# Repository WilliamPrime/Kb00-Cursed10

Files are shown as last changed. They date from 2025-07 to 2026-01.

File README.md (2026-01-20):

This was a shortish project where i wanted to make my own keyboard with my own layout.

The reason for wanting to do this was that i have limited desk space so i prefer a smaller more compact keyboard, so as of currently i use a 65% keyboard
however i do miss having a full size num pad and FN keys so i wanted to create a layout, and keyboard that would focus on getting a full key layout but making it more compact



# some pictures of the project

RENDER 1





# BOM

|part |cost  |notes |link |
|---|---|---|---|
|keycaps |19.97 | |https://www.aliexpress.com/item/1005005981079053.html|
|PCB |43 |JLC! | |
|Switches|34.19 |clicky clicky! |https://www.aliexpress.com/item/1005007779640100.html|
|Diodes  |3.1 |need 2 lots of 1.55 |https://www.aliexpress.com/item/1005006127068810.html|
|PI pico |2.17  |pico with usb type c|https://www.aliexpress.com/item/1005003753933847.html|
|PLA |0 |using my own | |
|Sum |111.61| | |

total cost $102.43

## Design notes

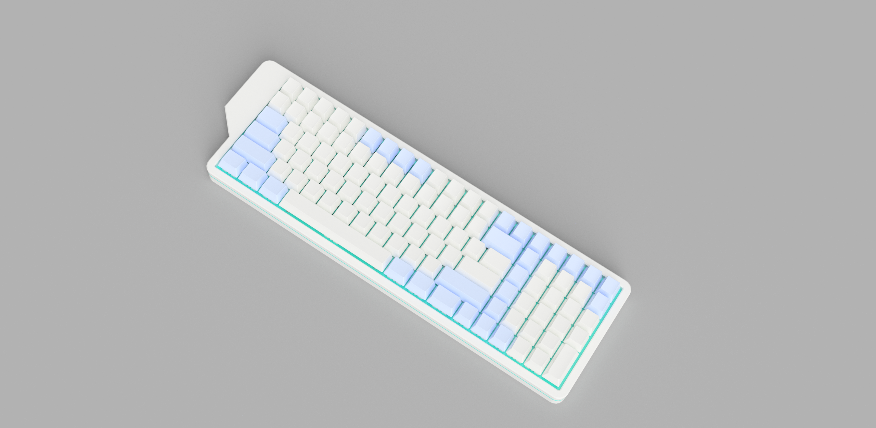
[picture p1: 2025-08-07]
IMGS/RENDERS/aqua plate pic2.png

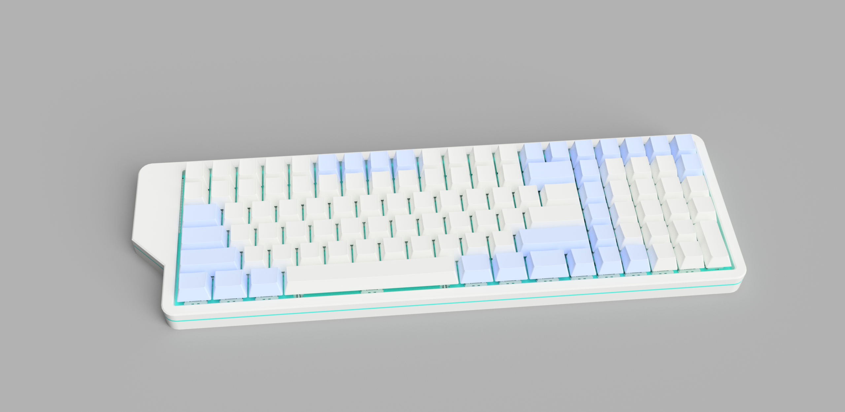
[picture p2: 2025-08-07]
IMGS/RENDERS/aqua plate.png

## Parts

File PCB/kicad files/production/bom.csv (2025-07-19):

Designator | Footprint | Quantity | Value | LCSC Part #
D1, D10, D101, D102, D103, D106, D11, D110, D111, D112, D115, D116, D117, D118, D119, D12, D120, D13, D14, D15, D16, D17, D18, D19, D2, D20, D21, D22, D23, D24, D25, D26, D27, D28, D29, D3, D30, D31, D32, D33, D35, D36, D37, D38, D39, D4, D40, D41, D42, D43, D44, D45, D46, D47, D48, D49, D5, D50, D51, D52, D53, D55, D56, D57, D58, D59, D6, D60, D61, D62, D63, D64, D65, D66, D67, D68, D69, D7, D70, D71, D72, D75, D76, D77, D78, D79, D8, D80, D81, D82, D83, D84, D85, D86, D87, D88, D89, D9, D90, D91, D95, D96, D97, D98, D99 | D_DO-35_SOD27_P7.62mm_Horizontal | 105 | Diode
S1, S10, S101, S102, S103, S106, S11, S110, S111, S112, S115, S116, S117, S118, S119, S12, S120, S13, S14, S15, S16, S17, S18, S19, S2, S20, S21, S22, S23, S24, S25, S26, S27, S28, S29, S3, S30, S31, S32, S33, S35, S36, S37, S38, S39, S4, S40, S41, S42, S43, S44, S45, S46, S47, S48, S49, S5, S50, S51, S52, S53, S55, S56, S57, S58, S59, S6, S60, S61, S62, S63, S64, S65, S66, S67, S68, S69, S7, S70, S71, S72, S75, S76, S77, S78, S79, S8, S80, S81, S82, S83, S84, S85, S86, S87, S88, S89, S9, S90, S91, S95, S96, S97, S98, S99 | SW_Cherry_MX_PCB_1.00u | 105 | Keyswitch
U1 | Raspberry_Pi_Pico | 1 | Raspberry_Pi_Pico

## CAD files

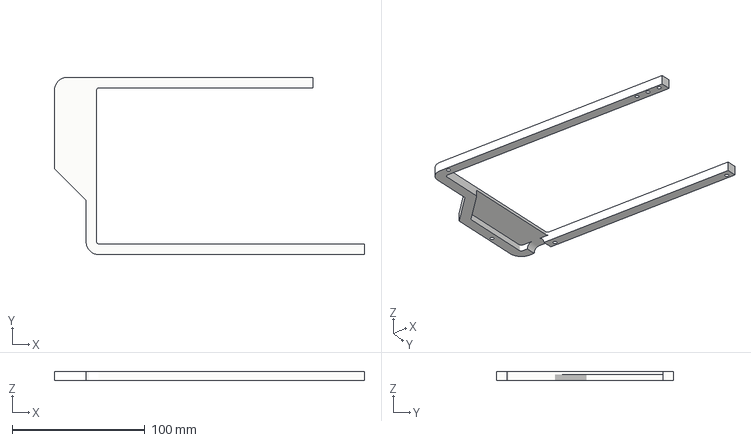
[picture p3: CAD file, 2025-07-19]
production/stls/Top A.3mf
233.9 x 133.8 x 7.00 mm

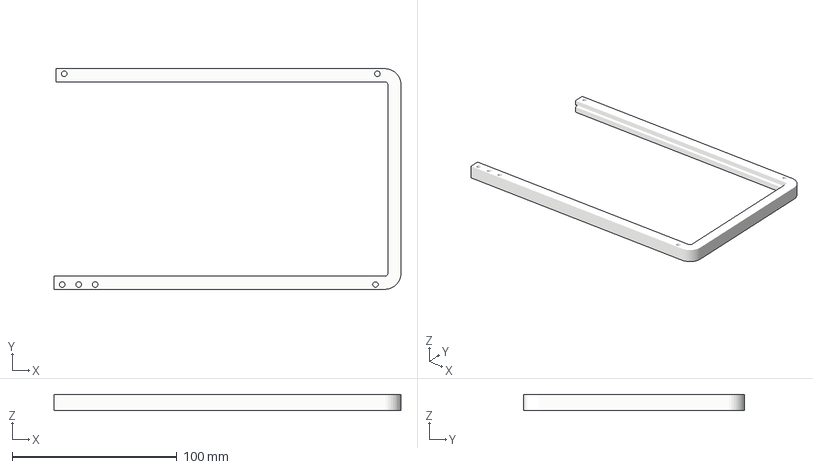
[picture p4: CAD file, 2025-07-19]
production/stls/Bottom B.3mf
210.5 x 133.8 x 10.0 mm

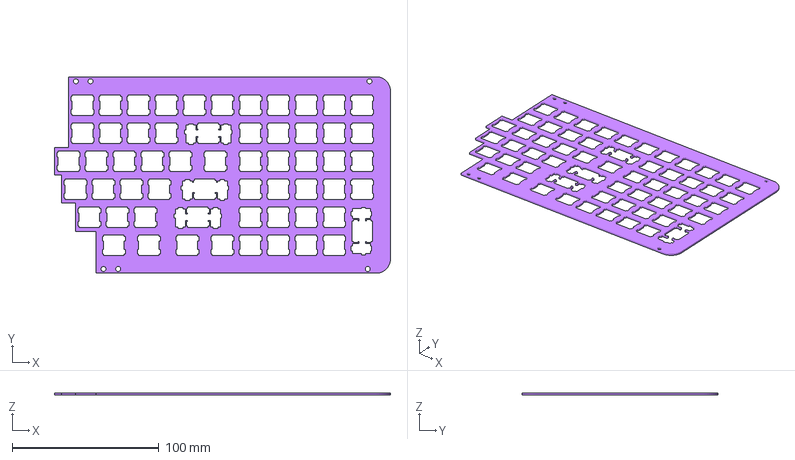
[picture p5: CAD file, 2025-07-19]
production/stls/Plate B.3mf
228.8 x 133.8 x 1.50 mm

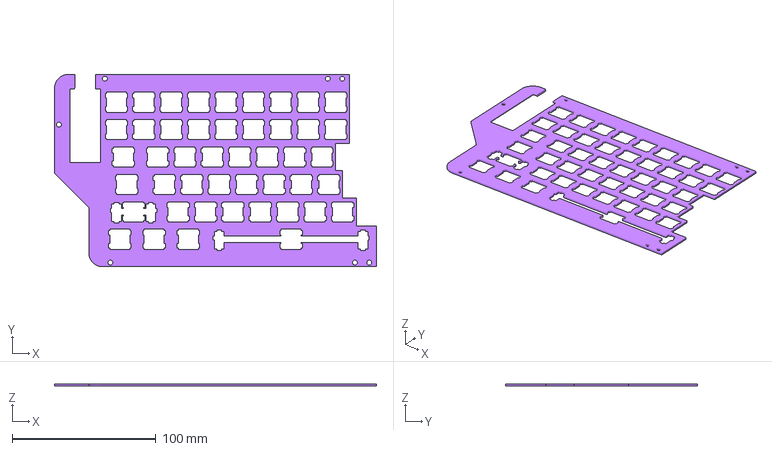
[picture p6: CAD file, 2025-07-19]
production/stls/Plate A.3mf
223.9 x 133.8 x 1.50 mm

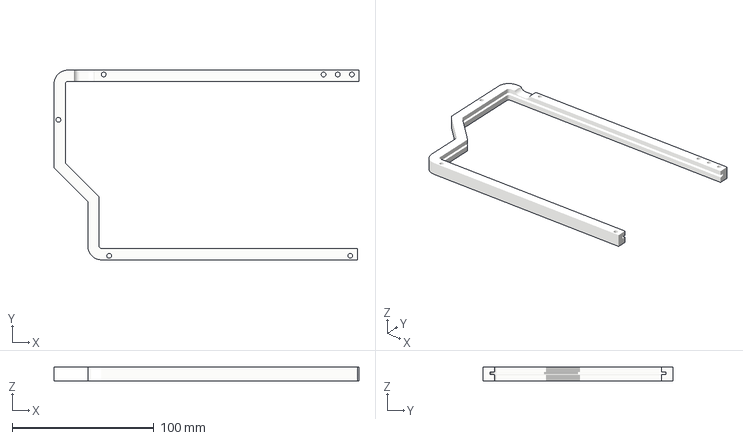
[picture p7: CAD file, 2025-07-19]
production/stls/Bottom A.3mf
215.0 x 133.8 x 10.0 mm

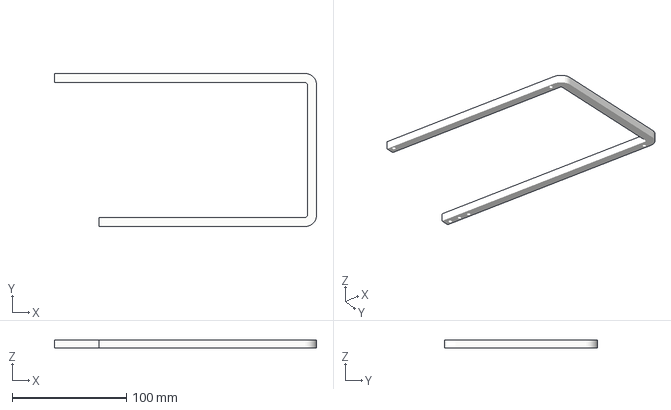
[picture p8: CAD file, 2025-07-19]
production/stls/Top B.3mf
229.3 x 133.8 x 7.00 mm

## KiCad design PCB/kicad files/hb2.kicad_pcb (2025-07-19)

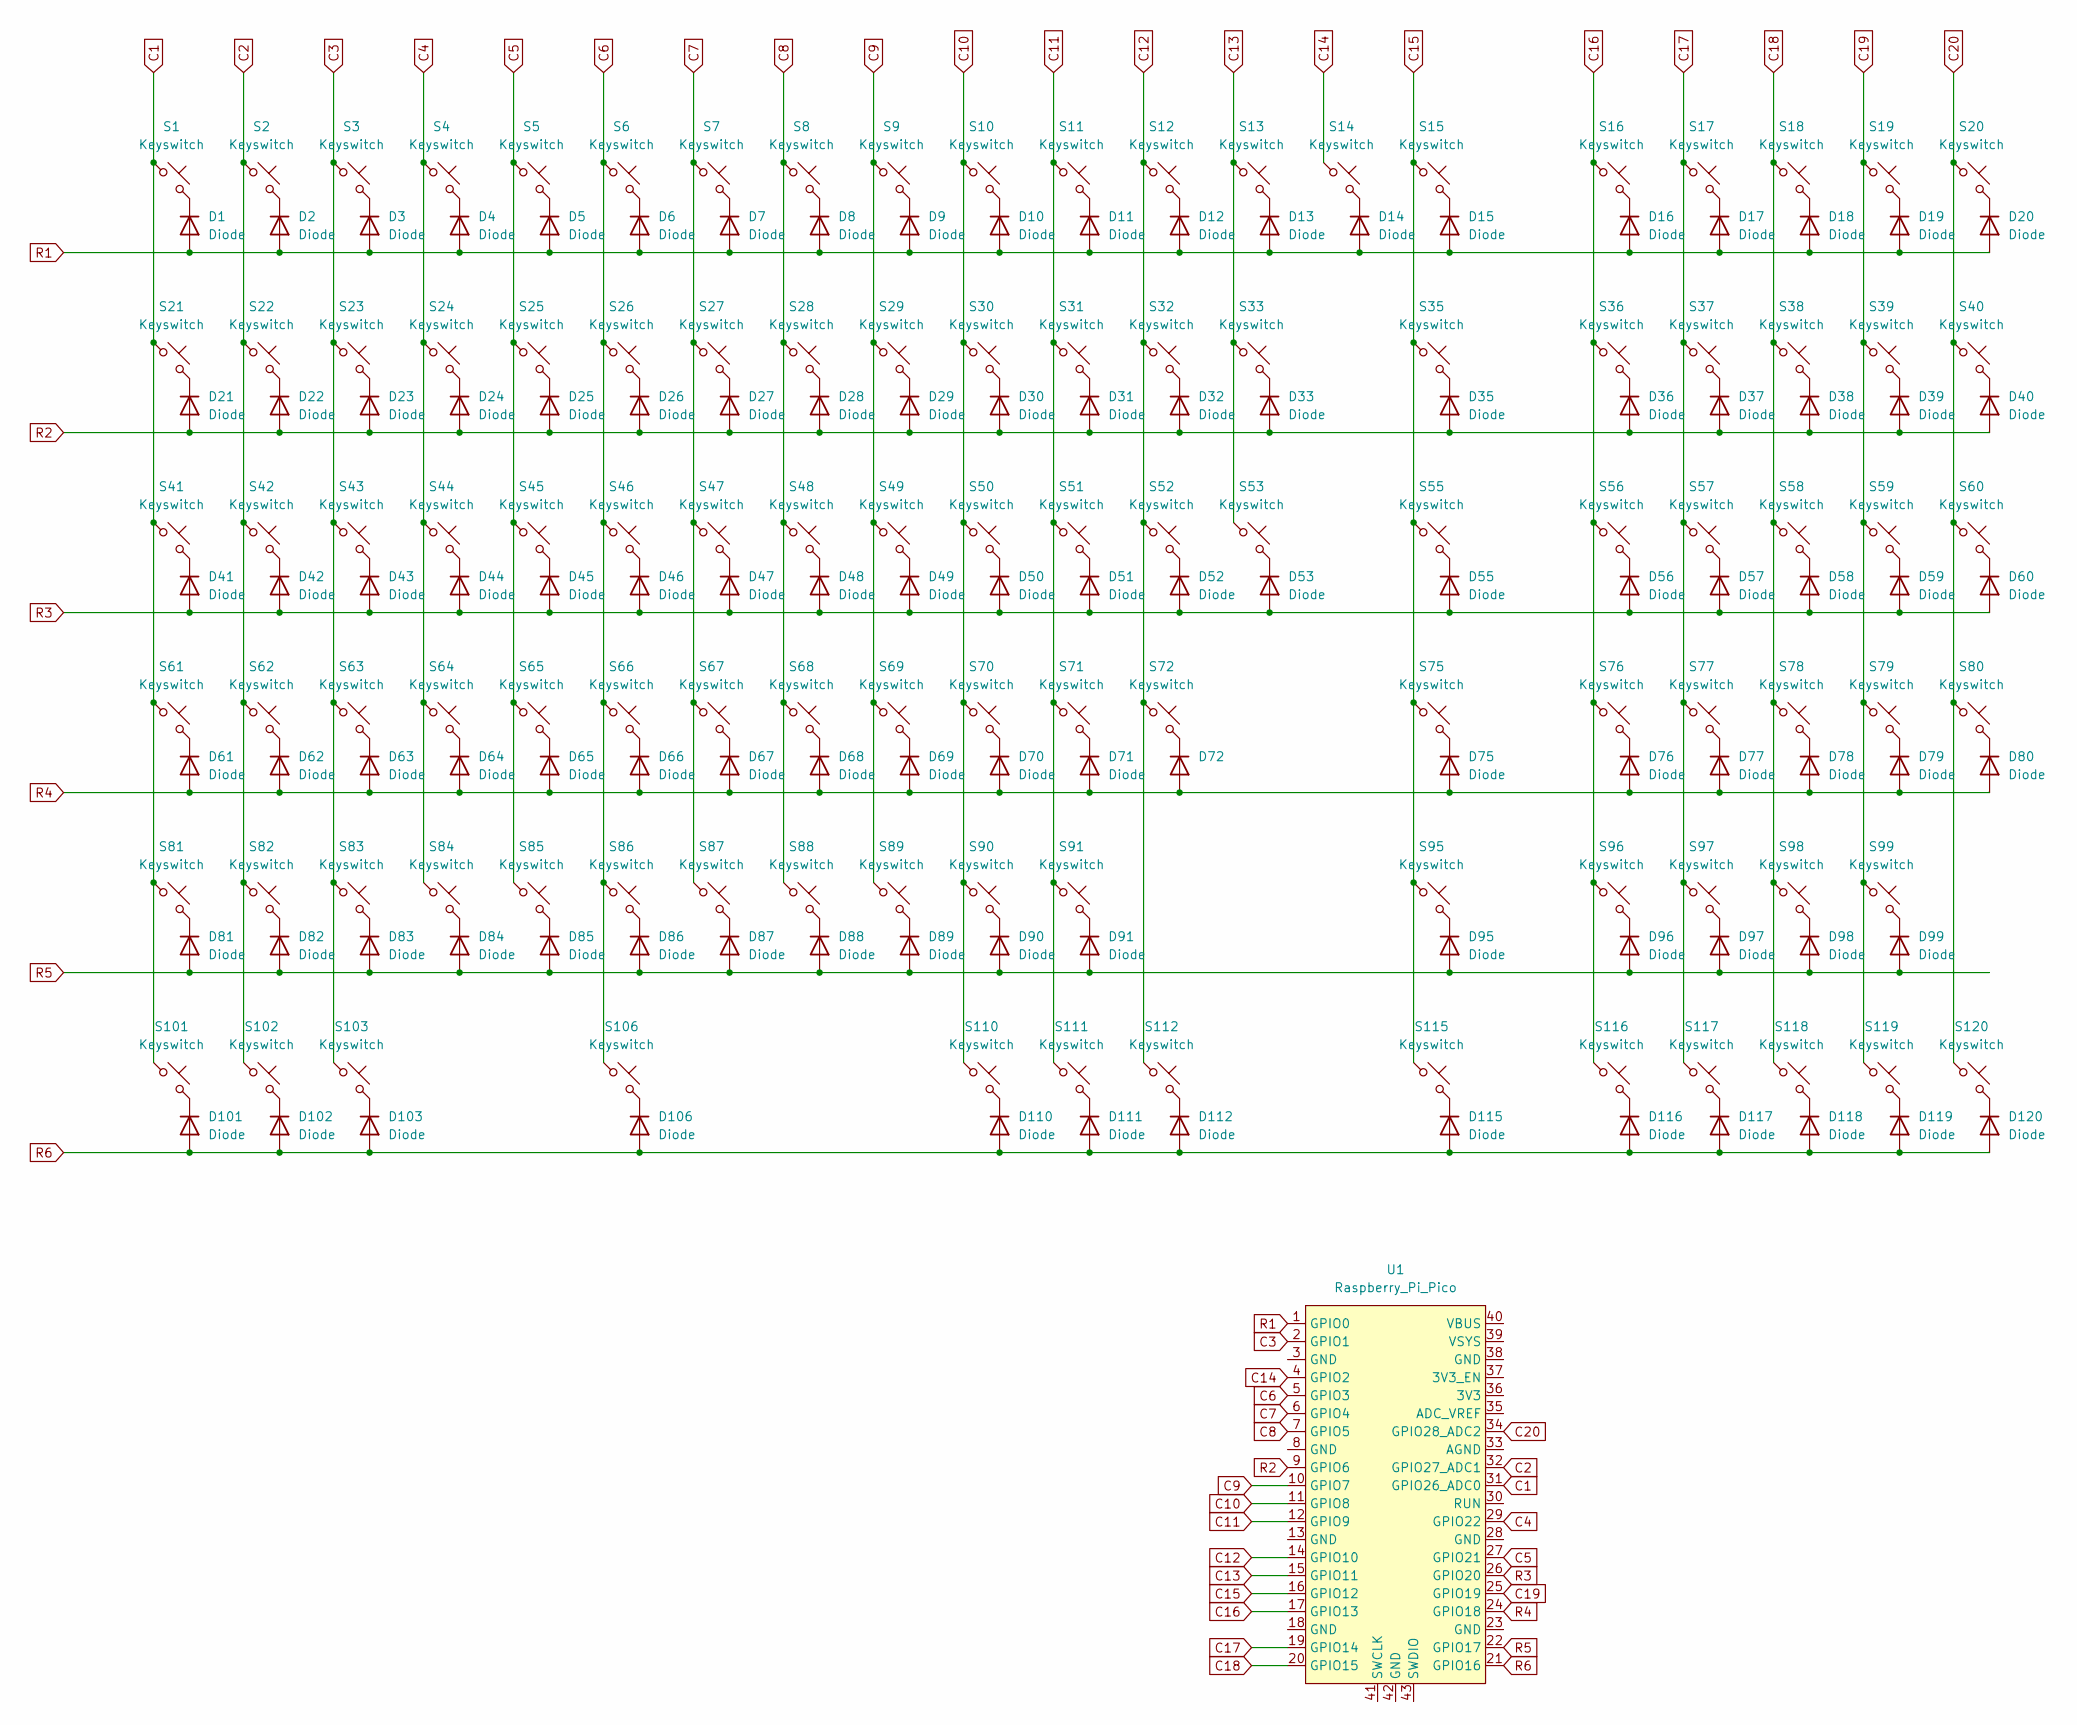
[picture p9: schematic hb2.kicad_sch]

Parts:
D1, D2, D3, D4, D5, D6, D7, D8, D9, D10, D11, D12, D13, D14, D15, D16, D17, D18, D19, D20, D21, D22, D23, D24, D25, D26, D27, D28, D29, D30, D31, D32, D33, D35, D36, D37, D38, D39, D40, D41, D42, D43, D44, D45, D46, D47, D48, D49, D50, D51, D52, D53, D55, D56, D57, D58, D59, D60, D61, D62, D63, D64, D65, D66, D67, D68, D69, D70, D71, D72, D75, D76, D77, D78, D79, D80, D81, D82, D83, D84, D85, D86, D87, D88, D89, D90, D91, D95, D96, D97, D98, D99, D101, D102, D103, D106, D110, D111, D112, D115, D116, D117, D118, D119, D120: Diode; D_DO-35_SOD27_P7.62mm_Horizontal
S1, S2, S3, S4, S5, S6, S7, S8, S9, S10, S11, S12, S13, S14, S15, S16, S17, S18, S19, S20, S21, S22, S23, S24, S25, S26, S27, S28, S29, S30, S31, S32, S33, S35, S36, S37, S38, S39, S40, S41, S42, S43, S44, S45, S46, S47, S48, S49, S50, S51, S52, S53, S55, S56, S57, S58, S59, S60, S61, S62, S63, S64, S65, S66, S67, S68, S69, S70, S71, S72, S75, S76, S77, S78, S79, S80, S81, S82, S83, S84, S85, S86, S87, S88, S89, S90, S91, S95, S96, S97, S98, S99, S101, S102, S103, S106, S110, S111, S112, S115, S116, S117, S118, S119, S120: Keyswitch; SW_Cherry_MX_PCB_1.00u
U1: Raspberry_Pi_Pico

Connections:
C1: S1.1, S21.1, S41.1, S61.1, S81.1, S101.1, U1.31 (GPIO26_ADC0)
C2: S2.1, S22.1, S42.1, S62.1, S82.1, S102.1, U1.32 (GPIO27_ADC1)
C3: S3.1, S23.1, S43.1, S63.1, S83.1, S103.1, U1.2 (GPIO1)
C4: S4.1, S24.1, S44.1, S64.1, S84.1, U1.29 (GPIO22)
C5: S5.1, S25.1, S45.1, S65.1, S85.1, U1.27 (GPIO21)
C6: S6.1, S26.1, S46.1, S66.1, S86.1, S106.1, U1.5 (GPIO3)
C7: S7.1, S27.1, S47.1, S67.1, S87.1, U1.6 (GPIO4)
C8: S8.1, S28.1, S48.1, S68.1, S88.1, U1.7 (GPIO5)
C9: S9.1, S29.1, S49.1, S69.1, S89.1, U1.10 (GPIO7)
C10: S10.1, S30.1, S50.1, S70.1, S90.1, S110.1, U1.11 (GPIO8)
C11: S11.1, S31.1, S51.1, S71.1, S91.1, S111.1, U1.12 (GPIO9)
C12: S12.1, S32.1, S52.1, S72.1, S112.1, U1.14 (GPIO10)
C13: S13.1, S33.1, S53.1, U1.15 (GPIO11)
C14: S14.1, U1.4 (GPIO2)
C15: S15.1, S35.1, S55.1, S75.1, S95.1, S115.1, U1.16 (GPIO12)
C16: S16.1, S36.1, S56.1, S76.1, S96.1, S116.1, U1.17 (GPIO13)
C17: S17.1, S37.1, S57.1, S77.1, S97.1, S117.1, U1.19 (GPIO14)
C18: S18.1, S38.1, S58.1, S78.1, S98.1, S118.1, U1.20 (GPIO15)
C19: S19.1, S39.1, S59.1, S79.1, S99.1, S119.1, U1.25 (GPIO19)
C20: S20.1, S40.1, S60.1, S80.1, S120.1, U1.34 (GPIO28_ADC2)
unnamed: D1.1 (K), S1.2
unnamed: D2.1 (K), S2.2
unnamed: D3.1 (K), S3.2
unnamed: D4.1 (K), S4.2
unnamed: D5.1 (K), S5.2
unnamed: D6.1 (K), S6.2
unnamed: D7.1 (K), S7.2
unnamed: D8.1 (K), S8.2
unnamed: D9.1 (K), S9.2
unnamed: D10.1 (K), S10.2
unnamed: D11.1 (K), S11.2
unnamed: D12.1 (K), S12.2
unnamed: D13.1 (K), S13.2
unnamed: D14.1 (K), S14.2
unnamed: D15.1 (K), S15.2
unnamed: D16.1 (K), S16.2
unnamed: D17.1 (K), S17.2
unnamed: D18.1 (K), S18.2
unnamed: D19.1 (K), S19.2
unnamed: D20.1 (K), S20.2
unnamed: D21.1 (K), S21.2
unnamed: D22.1 (K), S22.2
unnamed: D23.1 (K), S23.2
unnamed: D24.1 (K), S24.2
unnamed: D25.1 (K), S25.2
unnamed: D26.1 (K), S26.2
unnamed: D27.1 (K), S27.2
unnamed: D28.1 (K), S28.2
unnamed: D29.1 (K), S29.2
unnamed: D30.1 (K), S30.2
unnamed: D31.1 (K), S31.2
unnamed: D32.1 (K), S32.2
unnamed: D33.1 (K), S33.2
unnamed: D35.1 (K), S35.2
unnamed: D36.1 (K), S36.2
unnamed: D37.1 (K), S37.2
unnamed: D38.1 (K), S38.2
unnamed: D39.1 (K), S39.2
unnamed: D40.1 (K), S40.2
unnamed: D41.1 (K), S41.2
unnamed: D42.1 (K), S42.2
unnamed: D43.1 (K), S43.2
unnamed: D44.1 (K), S44.2
unnamed: D45.1 (K), S45.2
unnamed: D46.1 (K), S46.2
unnamed: D47.1 (K), S47.2
unnamed: D48.1 (K), S48.2
unnamed: D49.1 (K), S49.2
unnamed: D50.1 (K), S50.2
unnamed: D51.1 (K), S51.2
unnamed: D52.1 (K), S52.2
unnamed: D53.1 (K), S53.2
unnamed: D55.1 (K), S55.2
unnamed: D56.1 (K), S56.2
unnamed: D57.1 (K), S57.2
unnamed: D58.1 (K), S58.2
unnamed: D59.1 (K), S59.2
unnamed: D60.1 (K), S60.2
unnamed: D61.1 (K), S61.2
unnamed: D62.1 (K), S62.2
unnamed: D63.1 (K), S63.2
unnamed: D64.1 (K), S64.2
unnamed: D65.1 (K), S65.2
unnamed: D66.1 (K), S66.2
unnamed: D67.1 (K), S67.2
unnamed: D68.1 (K), S68.2
unnamed: D69.1 (K), S69.2
unnamed: D70.1 (K), S70.2
unnamed: D71.1 (K), S71.2
unnamed: D72.1 (K), S72.2
unnamed: D75.1 (K), S75.2
unnamed: D76.1 (K), S76.2
unnamed: D77.1 (K), S77.2
unnamed: D78.1 (K), S78.2
unnamed: D79.1 (K), S79.2
unnamed: D80.1 (K), S80.2
unnamed: D81.1 (K), S81.2
unnamed: D82.1 (K), S82.2
unnamed: D83.1 (K), S83.2
unnamed: D84.1 (K), S84.2
unnamed: D85.1 (K), S85.2
unnamed: D86.1 (K), S86.2
unnamed: D87.1 (K), S87.2
unnamed: D88.1 (K), S88.2
unnamed: D89.1 (K), S89.2
unnamed: D90.1 (K), S90.2
unnamed: D91.1 (K), S91.2
unnamed: D95.1 (K), S95.2
unnamed: D96.1 (K), S96.2
unnamed: D97.1 (K), S97.2
unnamed: D98.1 (K), S98.2
unnamed: D99.1 (K), S99.2
unnamed: D101.1 (K), S101.2
unnamed: D102.1 (K), S102.2
unnamed: D103.1 (K), S103.2
unnamed: D106.1 (K), S106.2
unnamed: D110.1 (K), S110.2
unnamed: D111.1 (K), S111.2
unnamed: D112.1 (K), S112.2
unnamed: D115.1 (K), S115.2
unnamed: D116.1 (K), S116.2
unnamed: D117.1 (K), S117.2
unnamed: D118.1 (K), S118.2
unnamed: D119.1 (K), S119.2
unnamed: D120.1 (K), S120.2
R1: D1.2 (A), D2.2 (A), D3.2 (A), D4.2 (A), D5.2 (A), D6.2 (A), D7.2 (A), D8.2 (A), D9.2 (A), D10.2 (A), D11.2 (A), D12.2 (A), D13.2 (A), D14.2 (A), D15.2 (A), D16.2 (A), D17.2 (A), D18.2 (A), D19.2 (A), D20.2 (A), U1.1 (GPIO0)
R2: D21.2 (A), D22.2 (A), D23.2 (A), D24.2 (A), D25.2 (A), D26.2 (A), D27.2 (A), D28.2 (A), D29.2 (A), D30.2 (A), D31.2 (A), D32.2 (A), D33.2 (A), D35.2 (A), D36.2 (A), D37.2 (A), D38.2 (A), D39.2 (A), D40.2 (A), U1.9 (GPIO6)
R3: D41.2 (A), D42.2 (A), D43.2 (A), D44.2 (A), D45.2 (A), D46.2 (A), D47.2 (A), D48.2 (A), D49.2 (A), D50.2 (A), D51.2 (A), D52.2 (A), D53.2 (A), D55.2 (A), D56.2 (A), D57.2 (A), D58.2 (A), D59.2 (A), D60.2 (A), U1.26 (GPIO20)
R4: D61.2 (A), D62.2 (A), D63.2 (A), D64.2 (A), D65.2 (A), D66.2 (A), D67.2 (A), D68.2 (A), D69.2 (A), D70.2 (A), D71.2 (A), D72.2 (A), D75.2 (A), D76.2 (A), D77.2 (A), D78.2 (A), D79.2 (A), D80.2 (A), U1.24 (GPIO18)
R5: D81.2 (A), D82.2 (A), D83.2 (A), D84.2 (A), D85.2 (A), D86.2 (A), D87.2 (A), D88.2 (A), D89.2 (A), D90.2 (A), D91.2 (A), D95.2 (A), D96.2 (A), D97.2 (A), D98.2 (A), D99.2 (A), U1.22 (GPIO17)
R6: D101.2 (A), D102.2 (A), D103.2 (A), D106.2 (A), D110.2 (A), D111.2 (A), D112.2 (A), D115.2 (A), D116.2 (A), D117.2 (A), D118.2 (A), D119.2 (A), D120.2 (A), U1.21 (GPIO16)

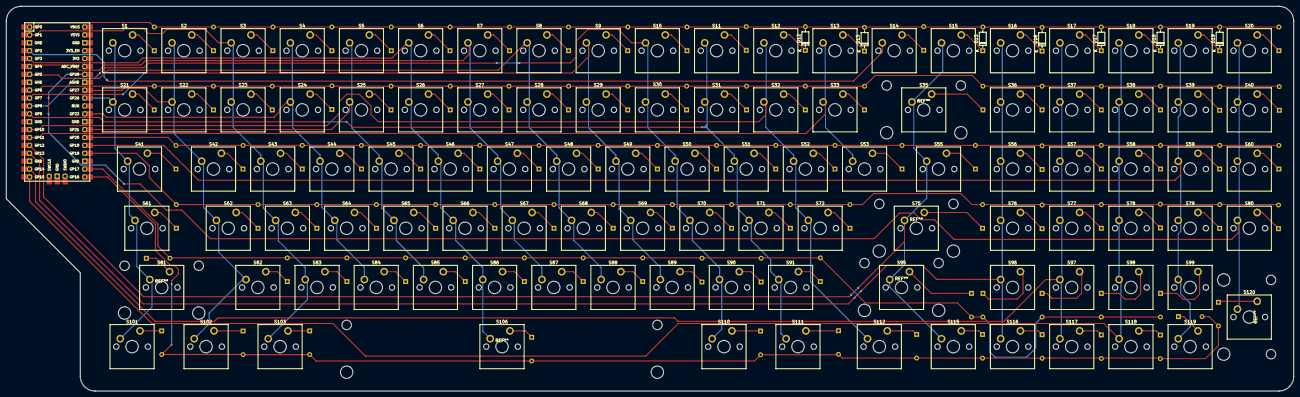
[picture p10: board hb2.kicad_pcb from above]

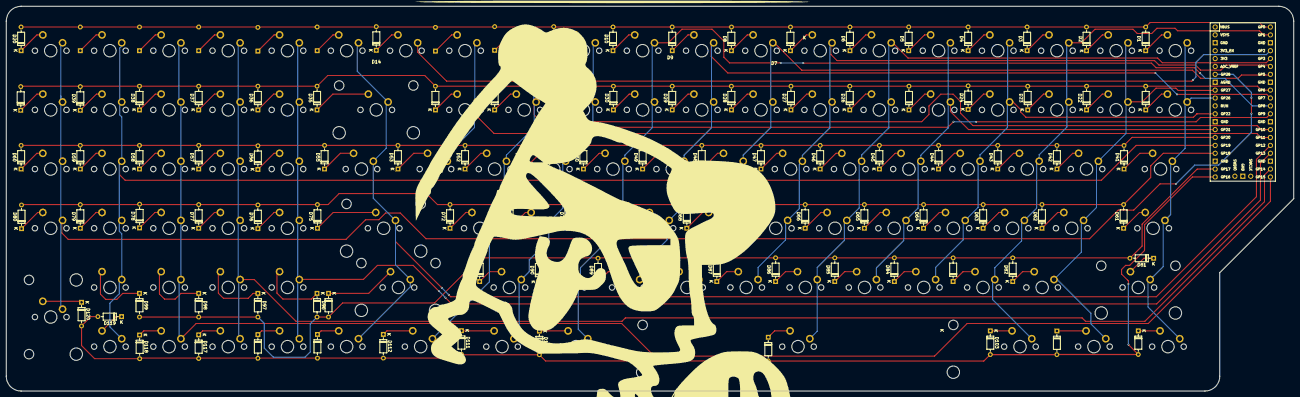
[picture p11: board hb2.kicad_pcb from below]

Board: 2 copper layers, 414.3 x 123.8 mm, 211 parts (98 on the bottom side), 131 nets.

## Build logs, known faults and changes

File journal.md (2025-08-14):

---
title: "The more cursed the more better"
author: "William Wallace"
description: "a really cursed keyboard with an extra cursed layout"
created_at: "2025-07-17"
---

Note: despite me putting created as the current date, i have been working on this for a month or so, i just put the date i actually started uploading this to github

so i started working on this RIGHT at the start of infil

# total time : 20.5 hours (this is a consvative approximation)
this also doesnt include it the time spent trying to mess arroudn with learning git 
(ive also not done it by date, but by day, and removing the gaps...)

# day 1-3    time: 2 hours

trying a few different layouts in keyboard layout editor.
my goals with this were to create a keyboard that met all the following:
- as compact as possible
-   avoid things i dont need like knobs etc
- a fullsize layout but compacted and with additional keys

here are some of the layouts that i started thinking about
  
  

but ultimately i decided on this layout because i liked the no gaps look and given that im trying to make my keyboard as compact as possible while not loosing keys, this seems like a reallyyy cursed but acceptable solution for that problem.



# day 4 making a schematic on kicad    time: 1h 25min

this was a little tricky trying to make sure i double and tripple checked that i had all the switches i needed

# day 5 Starting to layout  the pcb    time: 2 hours
this day was truely painful, there is a reason there arent any pictures here

short version of this day is:
- focusing on the pcb
- REALLY FOCUSSING
- forgot to save
- windows black screen of deathed (its not even blue anymore, sad)
- lost this days progress 😭

# day 6 starting to layout the pcb part 2 ,  time: 1hour

after having done this task once allready the previous day it made it a lot faster this time as i had allready re learnt and remembered how to do stuff
(add images here)

so this one was a breeze
i also sort of work out what techniques i had to use to get all the correct spacing for the keyboard

# day 7-9 doing all the tracing and finishing the PCB  time: 3hours
there were a lot of traces
it turns a keyboard with a ton of keys has a ton of traces 
(add imgs here)

# day 10 - 14 the CAD  time: 6hours or so
the CAD was a bit of a struggle trying to get a way to mount the pcb while trying to minimise both the height of the keys, and any brims arround the edge of the board

so here is a final render of the full keyboard

but now for the "fun" of how we ended up here!


i decided to add keycaps because i wanted to see what the thing looked like all together


next part was the plate because i knew i was going for plate mount and then sandwich that (i hope im using the right terms lol)


then it was a case of fighting through the cad to try and balance the keyboard case border
and how easy it would be to get in the screws to hold it all together and make sure i can 3d print it in smaller parts 


in splitting up the case i decided to stagger everything to try and hope to hold it together well




then it was time for the really big challenge i predicted earlier
trying to get the screws  to go where i wanted them to !


now its the point where it gets hard
because i really didnt want a massive bordere arround my part
but i knew i needed screw to hold it together
and i really didnt want to go back to the PCB to add the holes so i had to get a lil creative designing


this solution left 0.2mm of plastic to hide the screw

fusion didnt feel as nice on the other side soo i ended up without timeline turned on because fusion wasnt happy
:pf: 
but i got a solution


oh yeah the pcb should mount slide into that groove
with the case sliding on from each side


this is it from the bottom
i just wanted to leave the buttom open because im curious how it will affect the sound of the keyboard

cross section of the solution i eneded up with for mounting the pcb


# 19/07/2025 firmware 5hours
i was told i should at least get some firmware done
this wasnt that fun

i was trying to follow the kmk docs at first but just kept getting lost and struggling to read them

then i tried to use POG to create some firmware however its pretty hard to follow some of the steps on there without the physical keyboard infront of you so i had to resort to manually filling in the coordmap which took a while

it was really just me not having experience an not knowing what i was doing, and going down pathways that werent going to work

in the end it should work and was satisfying ish

# 20/07/2025 BUYING PARTS

woooo this took probably 45min
just trying to enter the different addresses etc
BUT ITS ALL ORDERED
IM EXCITED
tysm so much Alex for getting me the HCB card quickly so i could utilise the aliexpress sale ✨

# 29/07/2025   the build process yipeeee     6 hours

started off by populating the plate
_DSC0238
_DSC0237-2
then trying to push all the pins to align with the PCB
this did take a few attempts as sometimes there were bent pins

however i found a good stratergy for avoiding this,
just take aout the singular switch with the bent pins,
use pliars to fix the bent pin
then put it back into the plate

taking the whole plate of switches out when 1 is bent is not a good idea  
oops

definetly didnt forget to add stabilisers the first time i did it 
oops
this the first time i had an issue with stabilsers (foreshadoweing intensifies)

https://youtu.be/y29UAdKmAMU?si=JdBHaC-ciiN0UJ09
probably a good time to throw in that youtube link aswell
a full video of me making the keyboard
well not fullll, there was a part at the start where i forgot to start the camera recording, but ooopsie

i later had issues with my stabilisers
which turned out to in one case be that the plate was putting pressure on the stabs which then causes tons of friction and the keys to stick
the other time was when i hadnt soldered the switches straight so once again there was friction

the build wasnt too painful
it was just the stabilisers that seemed to dislike me

# 31/07/2025 Software 7h
the flashing of the keyboard with firmware at first went great
tested the top row, perfect

tested the second row from the top, worked great, until i hit the enter key
i turned out i just made some errors in my kmk config
3 or 4 hours remapping the keyboard fixed this!!!

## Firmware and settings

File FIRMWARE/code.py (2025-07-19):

# Main Keyboard Configuration - v1.0.0
import board
import pog
# check if we just want to run the coord_mappping Assistant
if pog.coordMappingAssistant:
    from coordmaphelper import CoordMapKeyboard
    if __name__ == '__main__':
        CoordMapKeyboard().go()
    print("Exiting Coord Mapping Assistant Because of an error")
else:
    from kb import POGKeyboard
    # set the required features for you keyboard and keymap
    # add custom ones in the kb.py

    keyboard = POGKeyboard(features=pog.kbFeatures)

    # manage settings for our modules and extensions here
    keyboard.tapdance.tap_time = 200

    # Keymap
    import keymap
    keyboard.keymap = keymap.keymap

    # Encoder Keymap if available
    if pog.hasEncoders:
        keyboard.encoder_handler.map = keymap.encoderKeymap

    # Execute the keyboard loop
    if __name__ == '__main__':
        keyboard.go()

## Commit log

2025-07-19 added BOM
    [bom.csv]
2025-07-19 Acutally adding the CAD and PCB
    actually added what i meant to add the first time
    [bom.csv, designators.csv, hb2.kicad_pcb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]
2025-07-19 updated bom to indclude solder
    updated bom to inc solder
    also the prices keep changing :pf:
    [bom.csv]
